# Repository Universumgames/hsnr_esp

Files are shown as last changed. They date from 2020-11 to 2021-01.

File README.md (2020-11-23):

# Communication between Arduino Uno's through light

<sub>created by Tom Arlt, Florian Meyer, Henning Müller, Florian Körwer</sub>

This project is a simple Aduino Uno project for communication between two Arduinos via light and controlling them via a serial monitor.

## Installation
This project was created with PlatformIO, an extension for VS Code to write Arduino programs, compile and write the binaries to an Arduino.

To use our project, open the platformIO project, change the `upload_port` in `platformio.ini` to the port your arduino is plugged into and upload the program.

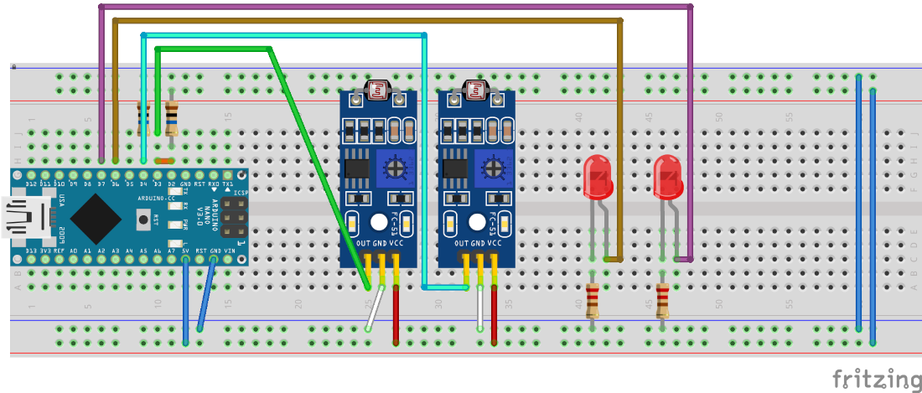
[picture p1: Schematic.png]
Wiring

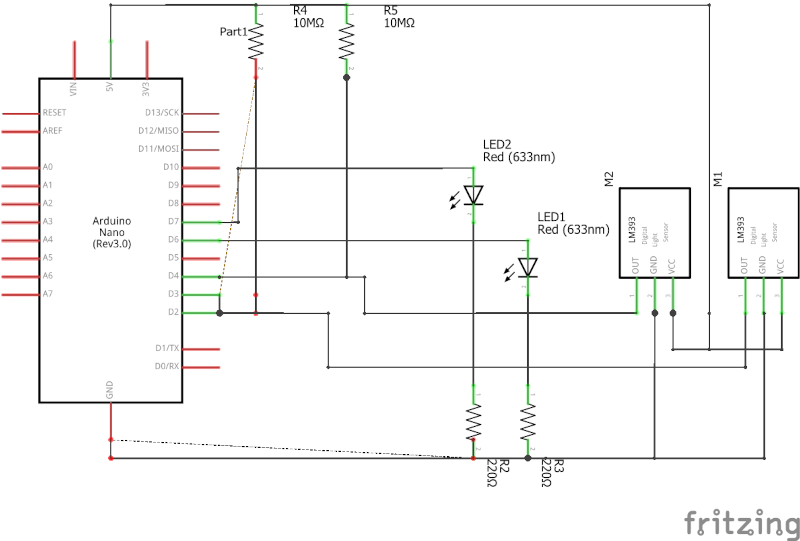
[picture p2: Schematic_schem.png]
Schematic


## Usage
1. Once uploaded, the arduino can communicate with another one as long as they are in LOS (Line of sight) and pointing directly at each other. The photoresistor should be facing the leds, to achieve that, the legs problably have to be bent.
2. Once placed correctly, you can start to open a serial monitor. You could use the integrated serial monitor in PlatformIO, the integrated serial monitor in the [Arduino IDE](https://www.arduino.cc/en/software) or [Putty](https://www.putty.org/), a great tool for using all kinds of connectivity like Serial, SSH, Raw, Telnet and Rlogin, or one of it's successors.
3. Select the Port your Arduino is plugged into, select the baud rate your arduino is sending/recieving to/from the serial monitor (the default is `9600`, but can be easily changed in `config.hpp`)
4. If everything works, you should be able to recieve encoded message from another Arduino and read the decoded result in your terminal, as well as write a message yourself and send it to the other Arduino.

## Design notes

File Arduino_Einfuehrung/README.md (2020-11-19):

# Arduino Einführung Aufgaben

## [Aufgaben-Datei](https://moodle.hsnr.de/pluginfile.php/640276/mod_resource/content/1/Anleitung_Kennenlernprojekte_WS2021_V3.pdf)

## Aufgabe 1

[Source-Code](https://git.ide3.de/universumgames/esp/-/tags/First-Task)

## Aufgabe 2

[Source-Code](https://git.ide3.de/universumgames/esp/-/tags/Second-Task)

## Aufgabe 3

[Source-Code](https://git.ide3.de/universumgames/esp/-/tags/Third-Task)

### 3 d) Geschwindigkeit von (Ultra-)Schall
Geschwindigkeit von Untraschall in Luft

    Mach 1 = 1234,8 km/h = 343 m/s

### 3 e)
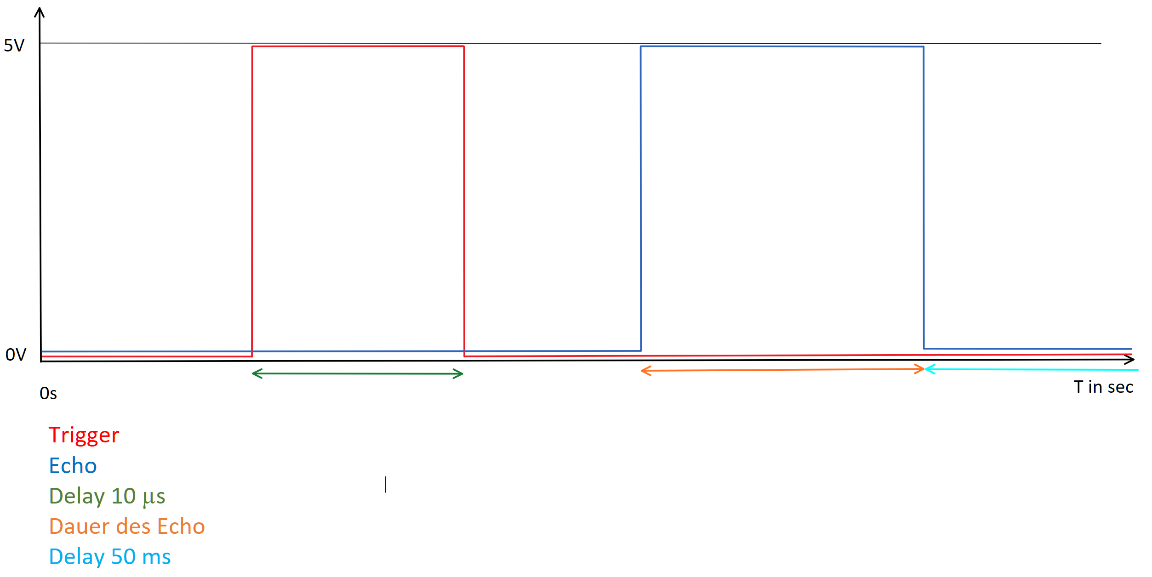
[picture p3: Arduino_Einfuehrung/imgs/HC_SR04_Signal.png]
HC-SR04 Signal

In der oben Abgebildeten Grafik ist ist die Verwendung bzw. eine Messung des HC-SR04 Ultraschallsensors abgebildet. In Rot dargestellt ist hierbei der `Trigger` Pin wohingegen Blau den `Echo` Pin repräsentiert. Nachdem der Trigger Pin für mindestens 10 µs auf 5V gesetzt wird, setzt der Sensor kurz darauf den Echo Pin ebenfalls auf 5V. In diesem Augenblich wird ein Ultrascahllsignal ausgesendet, sobald das Echo jenes gemessen wird, wird der Echo Pin wieder auf 0V gesetzt. Theoretisch kann der Ultraschallsensor mit einer Frequenz von maximal 50 Hz betrieben werden, welches einen Charge-Wechsel des Trigger Pins alle 20 ms bedeuten würde, jedoch kommt es in der Praxis immer auf die Entfernung und somit auf die Dauer des Echo Signals an, wie viel weniger häufig der Sensor die Entfernung pro Sekunde messen kann. Während die Frequenz, um es zu wiederholen, 50 Hz, ist die Amplitude des Signals bei 5V, die Periode läge bei einer Frequenz con 50 Hz somit bei 40 ms.

### 3 f) Ablauf einer Entfernungsmessung
Um die Entferung mittels Ultraschall messen zu können, wird im Prinzip ein kleiner Ultraschalllautsprecher und ein dazugehöriges Mikrofon verwendet. Der Mikrokontroller auf dem Entfernungsmesser sendet bei Eingang eines Signals über den `Trigger`-Pin Ultraschallwellen aus und empfängt ein Echo. Mithilfe der SChallgeschwindigkeit (343 m/s) und der vergangenen Zeit seitdem der Schall ausgesendet worden ist, kann die Entfernung zum Objekt unmittelbar (2-300cm) vor dem Ultraschallsensor errechnet werden. Das Ergebnis dieser Rechnung wird letztendlich über den `Echo`-Pin an den Arduino gesendet. Die `PulseIn()` Funktion des Arduinos wird beim Empfang des Signals verwendet, da die Daten nur über ein Kabel (`Echo`) gesendet werden und speziell "encodiert" sind. Der HC-SR04, so wie der Chip des Ultraschallsensors heißt, stellt den Pin `Echo` proportional (um den Wert 0.017) zur Entfernung auf HIGH (5V). Mithilfe der `PulseIn()` Methode des Arduinos kann die Dauert dieses Wertes gemessen werden und wird letzendlich von der Methode zurückgegeben.

## Aufgabe 4

[Source-Code](https://git.ide3.de/universumgames/esp/-/tags)

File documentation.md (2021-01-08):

# Dokumentation der Arduino Photokommunikation <br><sub>von Tom Arlt, Florian Körwer, Florian Meyer, Henning Müller, Cong Tai Phan <br><sub>Hochschule Niederrhein FB03, der 03.01.2021</sub></sub>

## Links
- [GitHub link](https://github.com/Universumgames/hsnr_esp)
- [IDE3 link](https://git.ide3.de/universumgames/esp)

## Einleitung
Unsere Aufgabe war es als Gruppe für das Erstsemesterprojekt, im folgenenden "ESP" genannt, zwei Arduinos mithilfe von Leds und Photoresistoren miteinander kommunizieren zu lassen und unsere Arbeit hiermit zu dokumentieren. <br>
Die notwendigen Bauteile wurden uns hierfür pro Person von der Hochschule zur Verfügung gestellt: 
- 1x Arduino Uno
- 2x LM392 mit Photoresistor und Potenziometer
- 1x Breadboard
- 2x 330 Ohm Widerstände
- verschied. LEDs
- verschied. Kabel für das Breadboard
- <s>1x Potenziometer</s>
- <s>1x Ultraschallsensor</s>

Da der Wissensstand innerhalb der Gruppe zum Thema Arduino sehr verschieden war, wurde nur zeitgleich und immer gemeinsam gearbeitet. Die Teilenhmer, welche bereits einiges an Erfahrung mit sich brachten, fungierten eher als Lehrpersonen, die den anderen das nötige Wissen überschaubar vermittelt haben, sodass alle dann gemeinsam die Aufgaben bearbeiten konnten.

## Lösung der Aufgabe
### Strategie
Das Entwickeln der Strategie für die Kommunikation, zu versuchen bereits bestehende Protokolle (als Basis) zu verwenden, war schnell erledigt. Der Versuch die nativen Protokolle des Arduinos zu verwenden scheiterte jedoch schnell, da alle Standardprotokolle viel zu schnell sind um mit LEDs verwendet werden zu können. Hinzukommt, dass uns zunächst entangen ist, dass der LM392 das Signal negiert ausgibt, welches uns erst einiges später auffiel. Schließlich entschlossen wir uns für eine serielle Kommunikation auf Basis des Protokolls [I2C](https://en.wikipedia.org/wiki/I%C2%B2C). Dieses Protokoll ist bei fast jedem modernen Microprocessor Hardwaremäßig implementiert für eine schneller Kommunikation. Bei diesem Protokoll ist in der Regel ein "Master" deklariert und mehrere "Slaves" welche alle gemeinsam an zwei Datenleitungen angeschlossen sind: "Data" und "Clock". Immer wenn die Spannung auf "Clock" von 0V auf 3.3/5V ändert wird auf "Data" der Zustand (Bit) abgelesen, bis sich letztendlich, nach einigen Takten ein Byte (8 Bit) ergeben. Das Standardprotokoll arbeitet eigentlich mit Adressen um zu differnezieren an wen und von wem die Nachricht gesendet wurde. <br>
Unser Protokoll übernimmt dabei nur das Prinzip von "Data" und "Clock", somit kann ein Empfangsmodul nur mit einem Sendermodul verbunden werden und vice versa.

### Unsere Hardware (Schematics)
Hier einmal die Schematics in der Arduino Schematic Software [fritzing](https://fritzing.org/)<br>



In dieser Schematic wurde der zum Arduino Uno funktionsidentische Arduino Nano verwendet und die Grafik übersitchlicher und kompakter zu gestalten. Beide Arduinoversionen besitzen denselben Prozessor (ATmega328P) und dieselben Pins. Die einzigen Unterschiede beider sind zum einen der Formfakor und zum anderen die Möglichkeit des Nanos, direkt auf ein Breadboard gesteckt werden zu können.
Dargestellt wurde hier ein einzelner Arduino, der in der Lage ist sowohl zu Empfangen als auch zu Senden, wenn das passend aufgebaute Gegenstück existiert.

### Software

Unser Programm wurde in C++ für die Arduino IDE geschrieben, schaue man sich frühere Commits an (vor dem 18.12.2020) wurde noch für eine andere IDE gechrieben: PaltformIO welche zwar auf der Arduino IDE basiert, jedoch hier nur eine Extension für die IDE VS Code ist. Einfacheitshalber wurde jedoch entgültig zur Arduino IDE gewechselt.

LED_SendSimple.ino
```cpp
//init variables
int LED = 2;
int incomingByte, ByteToSend;
int SerialCounter = -1;
//serial input buffer used as a stack
int SerialBuffer[10];
int MaxValue = 4;
int ClockCounter = 0;
boolean state = 0;
int BitsToSend = -1;

void setup() {
  //init serial interface
  Serial.begin(9600);
  pinMode(LED, OUTPUT);
}

void loop() {
  //read serial input if available
  if(Serial.available() > 0){
    incomingByte = Serial.read();
    if (incomingByte >= 32){
      //increment serial counter
      SerialCounter++;
      //store recieved byte from serial into stack buffer
      SerialBuffer[SerialCounter] = incomingByte;
    }
  }
  //theoratically the clockcounter could be removed and the delay in the last line set to 4*x
  ClockCounter++;
  if(ClockCounter >= MaxValue){
    ClockCounter = 0;
    state = !state;
    //if serial buffer is not empty
    if(SerialCounter > -1){
      //if current byte to send is not set
      if(BitsToSend <= -1){
        //set byte to send
        BitsToSend = SerialBuffer[SerialCounter];
        Serial.print("Sending byte: ");
        Serial.println(BitsToSend);
      }else{
        digitalWrite(LED, state);
        delay(70);
        //if led is on
        if(state){
          //decrease bit to send
          BitsToSend--;
          //if byte is sent, finish transmission
          if(BitsToSend <= 0){
            BitsToSend = -1;
            SerialCounter--;
            //wait same time as in outer loop, to avoid flickering of last count
            delay(4*70);
            digitalWrite(LED, LOW);
            delay(5000);
          }
        }
      }
    }
  }
  delay(70);
}
```

LED_RecieveSimple.ino
```cpp
//init variables
int LDR = 2;
int ClockCounter = 0;
int FlashCounter = 0;
int MaxValue = 2500;
int HighFlanke = 0;
int Flash;
unsigned long long lastmillis = 0;
int skippedMillis = 0;

void setup()
{
  //init serial monitor
  Serial.begin(9600);
  //init pinmode
  pinMode(LDR, INPUT);
}

void loop()
{
  ClockCounter++;
  //read LDR value
  Flash = digitalRead(LDR);
  //if led is off
  if (Flash)
  {
    HighFlanke = 1;
  }
  //if LDR value changes from HIGH to LOW
  if (!Flash && HighFlanke)
  {
    HighFlanke = 0;
    //increment flashcounter
    //account for glitches (glitches most often split a flash into two flashes)
    long delta = millis() - lastmillis;
    if (delta >= 500 || skippedMillis >= 500)
    {
      //increment counter and reset other variables
      FlashCounter++;
      ClockCounter = 0;
      skippedMillis = 0;
    }
    else
    {
      //to avoid glitches to impact transmission
      skippedMillis += delta;
    }
    //debug messages
    Serial.print(FlashCounter);
    Serial.print(": ");
    Serial.print(delta);
    Serial.print("ms ");
    Serial.println(skippedMillis);
    lastmillis = millis();
  }
  //if transmission for one character finished
  if (ClockCounter >= MaxValue && FlashCounter > 0)
  {
    //write flashcounter as character
    Serial.write(FlashCounter);
    //write ascii value
    Serial.println(FlashCounter);
    //reset flashcounter for next character
    FlashCounter = 0;
  }
  else
    delay(1);
}
```

#### Funktionsweise von Simple(Send/Recieve)
Die Funktionsweise von LED_SendSimple.ino basiert auf einer seriellen Datenübertragung. Um ein Zeichen zu übertragen wird dazu der byte Zahlenwert übermittelt. Dazu bleibt die LED x Millisekunden an und x Millisekunden aus, in unserem fall jeweils ca. 350. Nach vollständigem Durchzählen eines Bytes wird die Übertragung dieses mit einer sechs sekündigen Wartezeit abgeschlossen. <br>
Auf der Empfangsseite wird dabei auf ein eintreffendes Signal gewartet. Wenn mit einem Abstand von mindestens 500 ms ein Blinken erkannt wird, wir der derzeige Byte-Wert um eins erhöht, falls die Delta Zeit geringer ist, wird eine separate Variable erhöht. Durch das Verwenden der Deltazeit und dem Abfragen dieser zusätzliche Zeitvariable, wird der Einfluss von Glitches und Hazards bestmöglich minimiert. Bei einer Deltazeit von mehr als 2,5 Sekunden wird die Übteragung dieses Bytes abgeschlossen und dieser wird ausgegeben. 

LightCom.ino (LED_RecieveSynchron.ino + LED_SendSynchron) (eigene Lösung)
```cpp
//declare variables
//declare pins
int sender_clock = 5;
int sender_data = 6;
int reciever_clock = 2;
int reciever_clock_2 = 3;
int reciever_data = 4;

int incomingByte = 0;
long long last_millis = 0;
byte temp = 0;
int recieve_index = 7;
byte b = 0;
bool lastClockState = 0;

//declare timing
int ledDuration = 300;
int minSignalDur = 100;
int clDelay = 50;

void setup()
{
  //initialize Serial Monitor
  Serial.begin(9600);
  //set pin modes
  pinMode(sender_clock, OUTPUT);
  pinMode(sender_data, OUTPUT);
  pinMode(reciever_clock, INPUT);
  pinMode(reciever_clock_2, INPUT);
  pinMode(reciever_data, INPUT);
}

void loop()
{
  //check if serial queue contains items
  if (Serial.available() > 0)
  {
    //read incoming byte (characters)
    incomingByte = Serial.read();
    
    Serial.write(incomingByte);
    Serial.print(": ");
    Serial.print(incomingByte);
    Serial.print(" ");
    //send each bit seperately to serial monitor for debugging and to other arduino
    for (int i = 7; i >= 0; i--)
    {
      sendBit(bitRead(incomingByte, i));
    }
    Serial.println();
  }

//check for changes on clock pin
  bool state = !digitalRead(reciever_clock);
  if (state != lastClockState)
  {
     lastClockState = state;
     if (state == HIGH)
        clock_interrupt_start();
     else
        clock_interrupt_end();
  }
}

//read incoming bits
void clock_interrupt_start()
{
  bool dataval = !digitalRead(reciever_data);
  bitWrite(temp, recieve_index, dataval);
}

//verify incoming bit
void clock_interrupt_end()
{
  //calculate delta since clock fell, to check for hazards
  unsigned long delta = millis() - last_millis;
  //if delta > 100ms, it's nit a hazard or glitch from the photoresistor
  if (delta >= minSignalDur)
  {
    //write temporary byte to "longterm" byte
    b = temp;
    Serial.print(bitRead(b, recieve_index));
    //reduce recieve index to move to next bit
    recieve_index--;
    //if recieve_index < 0 we have successfully recieved a byte and print that to the serial monitor
    if (recieve_index < 0)
    {
      Serial.write(b);
      //reset recieving variables to default state
      recieve_index = 7;
      b = 0x0;
    }
    //reset for delta caluclation
    last_millis = millis();
  }
  else
  {
    //if a glitch was detected, delete temporarily recieved bit
    temp = b;
  }
}

//send single bit
void sendBit(bool bitt)
{
  Serial.print(bitt);
  //change data pin
  digitalWrite(sender_data, bitt);
  delay(clDelay);
  //change clock to HIGH
  digitalWrite(sender_clock, HIGH);
  //wait to be able to differentiate between valid bit and a hazard
  delay(ledDuration);
  //change both pins to default state
  digitalWrite(sender_clock, LOW);
  delay(clDelay);
  digitalWrite(sender_data, LOW);
  delay(ledDuration);
}

```

#### Funktionsweise von LightCom
Dieses Projekt ist ist für eine bidirektionale Kommunikation geeinget, d.h. beide Arduinos können miteinander kommunizieren. Die Kommunikation basiert auf dem simplen serieellen Protokoll namens I<sup>2</sup>C, bei dem zwei Verbindungen für eine serielle Datenübertragung verwendet werden. Diese Verbindungen heißen "Clock" und "Data" bzw. "SDA" (Serial Data) und "SCL" (Serial Clock). Bei der Modifikation dieses Protokolls wurde die Funktionsweise nicht verändert, jedoch musste das Verhalten des LDRs beachtet werden, da dieser Logisch negiert. Um nun einen Byte zu senden wird dieser Bitweise übertragen, dabei wird der MSB als erstes gesendet und die Übertragung eines Bytes endet mit dem LSB. Das Übermitteln eines einzelnen Bits erfolgt dabei wiefolgt: Die "Data"-LED wird auf den jeweiligen Wert des Bits gesetzt (HIGH für 1 und LOW für 0), nach einem kurzeln Delay, um sicherzustellen, dass die LED ihre gewünschte Helligkeit erreicht hat, wird die "Clock"-LED auf HIGH gesetzt, kurze Zeit später werden beide LEDs, unabhänging von ihrem vorherigen Zustand, wieder auf LOW gesetzt. Nach dem Empfangen von 8 Bits, bereits entsprechend dem MSB und LSB in einem Byte gespeichert, werden diese als ASCII Buchstabe auf dem Seriellen Monitor ausgegeben.

Link zum Aktuellen Programmcode: [Github](https://github.com/Universumgames/hsnr_esp/tree/master/LightCom), [IDE3](https://git.ide3.de/universumgames/esp/-/tree/master/LightCom) <br>
Link zum aufbereiteten/alternativen Code (eigenständig entwickelt von Tom Arlt):  [Github](https://github.com/Universumgames/hsnr_esp/tree/universumgames/LightCom), [IDE3](https://git.ide3.de/universumgames/esp/-/tree/universumgames/LightCom)

## Verwendung
(Übersetzt und aufbereitet aus [Readme.md](Readme.md))
Um unser Projekt zu verwenden, müssen zwei Schaltungen aufgebaut sein, wobei mindestens zwei LEDs und zwei Empfänger aufgebaut sein müssen, um zumindest die Einseitige Kommunikation testen zu können. Zu beachten ist, dass jedes LED-LM392 Paar zu allen anderen Paaren abgeschirmt sein sollte, da es sonst zu Interferrenzen kommen kann. Zudem muss das Potenziometer des LM392 eingestellt werden nur die dazugehörige eingeschaltete LED zu erkennen und nicht das Umgebungslicht. Bei der Erstellung der LED-LM392 Paare ist auf die Unterscheidung zwischen "Data" und "Clock" zu achten:
<pre>
Arduino 1       <-> Arduino 2
sender_clock    <-> reciever_clock
sender_data     <-> reciever_data
reciever_clock  <-> sender_clock
reciever_data   <-> sender_data
</pre>

Ist das Programm einmal auf beiden Arduinos hochgeladen, ist die Arduino IDE (o.ä.) nicht mehr notwendig. Nun kann über einen Seriellen Monitor, wie zum Beispiel der intergrierte Monitor der [Arduino IDE](https://www.arduino.cc/en/software) oder  [Putty](https://www.putty.org/) über den Arduino kommuniziert werden. In diesen Tools muss noch der Port, über den der Arduino angeschlossen ist, angegeben werden, sowie die Baud Rate des Seriellen Monitor, welche hier `9600` beträgt.

## Reflexion
Wie schon in `Strategie` erwähnt, war die grundsätzliche Strategie schnell gefunden, nur das ausarbeiten hat, dank der Rückschläge, etwas länger gedauert.
Nach den ersten Rückschlägen und das Festsetzen auf die entgültige Implementationsstrategie war auch das Entwickeln eines ersten Gerüsts relativ straight forward. Das Debuggen sowie ein ordentlicher Aufbau der Schaltung war dann die größere Herausforderung. Da durch ständig wechselnde Lichtverhältnisse der Photoresistor nicht immer wie gewünscht funktionierte, verzögerte sich das Programm-Debuggen ungemein. Erst nach vielen Stunden rumgrübelns, rumschrauben und ausprobieren, stellte sich als einzige zuverlässige Methode eine eigene Blackbox für jedes LED-LM392 Paar heraus. 

## Zusammenfassung
Die Aufgaben waren, wenn auch leicht missverständlich organisiert, einfach zu bearbeiten. Wir hatten schnell eine grundsätzliche Strategie für die Programmentwicklung gefunden und hatten binnen einiger Stunden nach den Fehlversuchen einen ersten ordentlichen Prototypen stehen. Somit hatten wir die grundsätzliche Aufgabe "zwei Arduinos mithilfe von LEDs und LDRs kommunizieren zu lassen" gelöst. Währenddessen sich die Ersten bereits an die Dokumentation gesetzt hatten, haben sich andere im Internet auf die Suche gemacht ein angemessenes Schematic-Tool ausfindig zu machen und eine digitale Schaltung zu erstellen.<br>
Erst später, als alle gemeinsam an der Dokumentation arbeiteten, fiel auf, dass die Aufgaben der Anleitung zum Kommunikationssystem zu bearbeiten sind. Als die Dokumentation bereits in den letzten Zügen war, wurden die zusätzlichen Aufgaben fertiggestellt, dabei schafften wir es jedoch nicht die Kommunikation der Arduinos mithilfe dieser Aufgaben über die digitalen Kommunikationswege erfolgreich zu realisieren, da die Photoresistoren die LEDs nur unzureichend erkennen konnten. Zusätzlich kamen noch Timingproblemen hinzu, die durch die Kommunikation entstanden sind.<br>
Ingesamt hat die Gruppe gut zusammengearbeitet und ist recht zügig zu einer ersten Lösung gekommen.

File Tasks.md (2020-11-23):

# Tasks
## 1. Arduino Einführung
Die einführenden Beispiel-Aufgaben sind beim zweiten Präsenztermin vorzuführen. D.h, jedes Gruppenmitglied hat die Schaltungen aufgebaut, den Arduino programmiert und kann das Ergebnis vorführen und erläutern.

## 2. Kommuniktaion zwischen zwei Arduinos
Aufgabe des Projekts ist es, eine optische Kommunikation aufzubauen. Dazu sollen mit einer oder mehrerer LEDs Informationen gesendet werden, in dem diese in einem bestimmten Muster ein- und ausgeschaltet werden. Ein optischer Sensor soll als Empfänger das Ein- und Ausschalten erkennen und die Informationen wiedergeben. 

### Dokumentation
Die Arbeiten zur optischen Kommunikation sind zu dokumentieren. Erstellen Sie als Gruppe ein Dokument (pdf) und laden es hier in Moodle eine Woche vor Ihrem dritten Präsenztermin hoch. Bitte halten Sie sich dabei an den folgenden Aufbau (ca. 5 Seiten):

- Titel der Dokumentation, Name der Hochschule/Fachbereich, Namen der Teammitglieder, Datum
- Einleitung (mit Aufgabenstellung)
- Aufgabenverteilung und Arbeitsweise in der Gruppe
- Wer hat was gemacht?
- Wurde nur gemeinsam gearbeitet oder gab es Arbeitspakete (z. B. zwei kümmern sich um den Sender und die anderen zwei um den Empfänger)?
- Beschreibung der Lösung
    - Strategie: verfolgte Lösungsidee
    - Hardware: Schaltplan
    - Software: Code mit Kommentaren
- Reflexion
    - Was hat gut funktioniert?
    - Was hat nicht so gut funktioniert und wie könnte man es beim nächsten Mal besser machen?
- Zusammenfassung

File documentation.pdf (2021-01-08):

documentation.md | 1/8/2021

# Dokumentation der Arduino Photokommunikation

von Tom Arlt, Florian Körwer, Florian Meyer, Henning Müller,

## Cong Tai Phan

## Hochschule Niederrhein FB03, der 03.01.2021

## Links

GitHub link (https://github.com/Universumgames/hsnr_esp)
IDE3 link (https://git.ide3.de/universumgames/esp)

## Einleitung

Unsere Aufgabe war es als Gruppe für das Erstsemesterprojekt, im folgenenden "ESP" genannt, zwei Arduinos mithilfe von Leds und Photoresistoren miteinander kommunizieren zu lassen und unsere Arbeit hiermit zu dokumentieren.
Die notwendigen Bauteile wurden uns hierfür pro Person von der Hochschule zur Verfügung gestellt:

1x Arduino Uno
2x LM392 mit Photoresistor und Potenziometer
1x Breadboard
2x 330 Ohm Widerstände
verschied. LEDs
verschied. Kabel für das Breadboard
1x Potenziometer
1x Ultraschallsensor

Da der Wissensstand innerhalb der Gruppe zum Thema Arduino sehr verschieden war, wurde nur zeitgleich und immer gemeinsam gearbeitet. Die Teilenhmer, welche bereits einiges an Erfahrung mit sich brachten, fungierten eher als Lehrpersonen, die den anderen das nötige Wissen überschaubar vermittelt haben, sodass alle dann gemeinsam die Aufgaben bearbeiten konnten.

## Lösung der Aufgabe

Strategie

Das Entwickeln der Strategie für die Kommunikation, zu versuchen bereits bestehende Protokolle (als Basis) zu verwenden, war schnell erledigt. Der Versuch die nativen Protokolle des Arduinos zu verwenden scheiterte jedoch schnell, da alle Standardprotokolle viel zu schnell sind um mit LEDs verwendet werden zu können. Hinzukommt, dass uns zunächst entangen ist, dass der LM392 das Signal negiert ausgibt, welches uns erst einiges später auffiel. Schließlich entschlossen wir uns für eine serielle Kommunikation auf Basis des Protokolls I2C. (https://en.wikipedia.org/wiki/I%C2%B2C) Dieses Protokoll ist bei fast jedem modernen Microprocessor Hardwaremäßig implementiert für eine schneller Kommunikation. Bei diesem Protokoll ist in der Regel ein "Master" deklariert und mehrere "Slaves" welche alle gemeinsam an zwei Datenleitungen angeschlossen sind: "Data" und "Clock". Immer wenn die Spannung auf "Clock" von 0V auf 3.3/5V ändert wird auf "Data" der Zustand (Bit) abgelesen, bis sich letztendlich, nach einigen Takten ein Byte (8 Bit) ergeben. Das Standardprotokoll arbeitet eigentlich mit Adressen um zu differnezieren an wen und von wem die Nachricht gesendet wurde.
Unser Protokoll übernimmt dabei nur das Prinzip von "Data" und "Clock", somit kann ein Empfangsmodul nur mit einem Sendermodul verbunden werden und vice versa.
Unsere Hardware (Schematics)

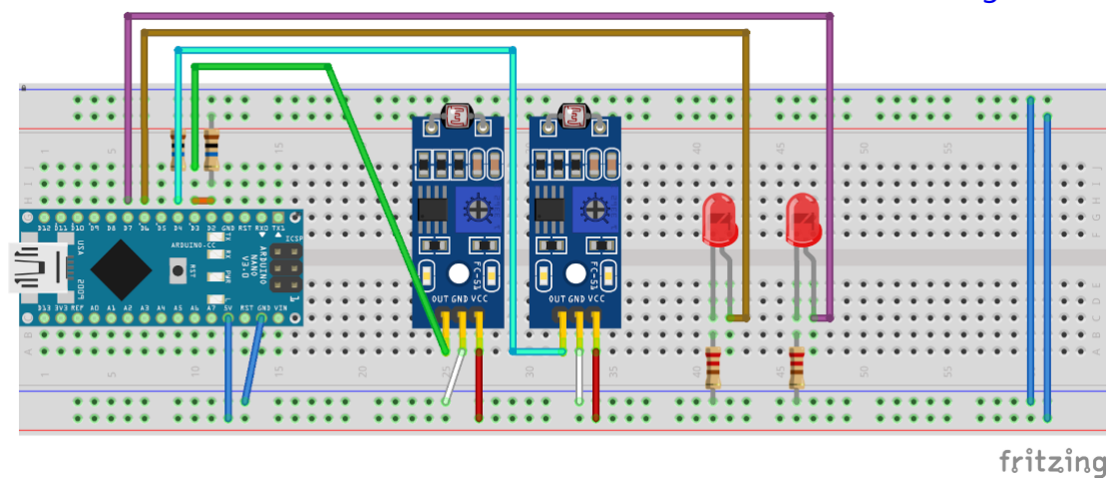
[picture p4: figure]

Hier einmal die Schematics in der Arduino Schematic Software fritzing (https://fritzing.org/)


In dieser Schematic wurde der zum Arduino Uno funktionsidentische Arduino Nano verwendet und die Grafik übersitchlicher und kompakter zu gestalten. Beide Arduinoversionen besitzen denselben Prozessor (ATmega328P) und dieselben Pins. Die einzigen Unterschiede beider sind zum einen der Formfakor und zum anderen die Möglichkeit des Nanos, direkt auf ein Breadboard gesteckt werden zu können. Dargestellt wurde hier ein einzelner Arduino, der in der Lage ist sowohl zu Empfangen als auch zu Senden, wenn das passend aufgebaute Gegenstück existiert.
Software

Unser Programm wurde in C++ für die Arduino IDE geschrieben, schaue man sich frühere Commits an (vor dem 18.12.2020) wurde noch für eine andere IDE gechrieben: PaltformIO welche zwar auf der Arduino IDE basiert, jedoch hier nur eine Extension für die IDE VS Code ist. Einfacheitshalber wurde jedoch entgültig zur Arduino IDE gewechselt.

LED_SendSimple.ino

//init variables
int LED = 2;
int incomingByte, ByteToSend;
int SerialCounter = -1;
//serial input buffer used as a stack int SerialBuffer[10];
int MaxValue = 4;
int ClockCounter = 0;
boolean state = 0;
int BitsToSend = -1;

void setup() {
//init serial interface
Serial.begin(9600);
pinMode(LED, OUTPUT);
}

void loop() {
//read serial input if available if(Serial.available() > 0){ incomingByte = Serial.read(); if (incomingByte >= 32){
//increment serial counter
SerialCounter++;
//store recieved byte from serial into stack buffer SerialBuffer[SerialCounter] = incomingByte;
}
}
//theoratically the clockcounter could be removed and the delay in the last line set to 4*x
ClockCounter++;
if(ClockCounter >= MaxValue){
ClockCounter = 0;
state = !state;
//if serial buffer is not empty if(SerialCounter > -1){
//if current byte to send is not set if(BitsToSend <= -1){
//set byte to send
BitsToSend = SerialBuffer[SerialCounter]; Serial.print("Sending byte: "); Serial.println(BitsToSend);
}else{
digitalWrite(LED, state);
delay(70);
//if led is on
if(state){
//decrease bit to send
BitsToSend--;
//if byte is sent, finish transmission if(BitsToSend <= 0){
BitsToSend = -1;

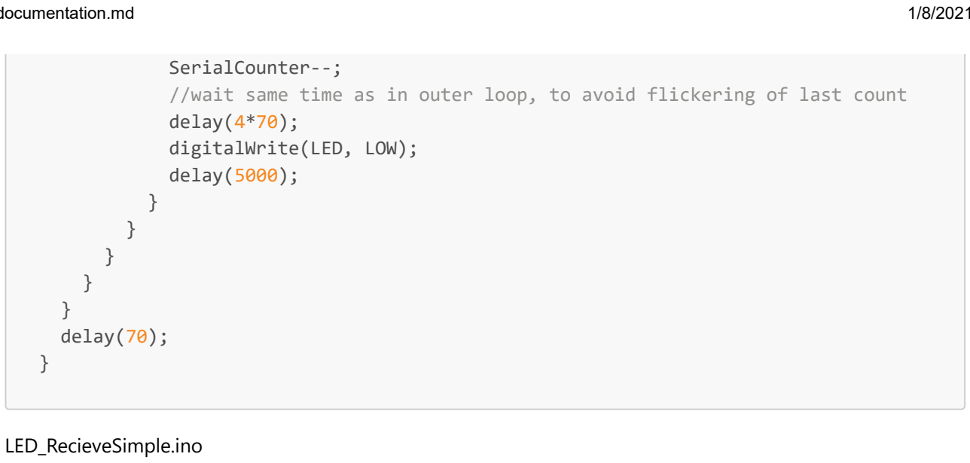
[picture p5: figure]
SerialCounter--;; delay(4*70); digitalWrite(LED, LOW); delay(5000);; } delay(70);; LED_RecieveSimple.ino

//wait same time as in outer loop, to avoid flickering of last count

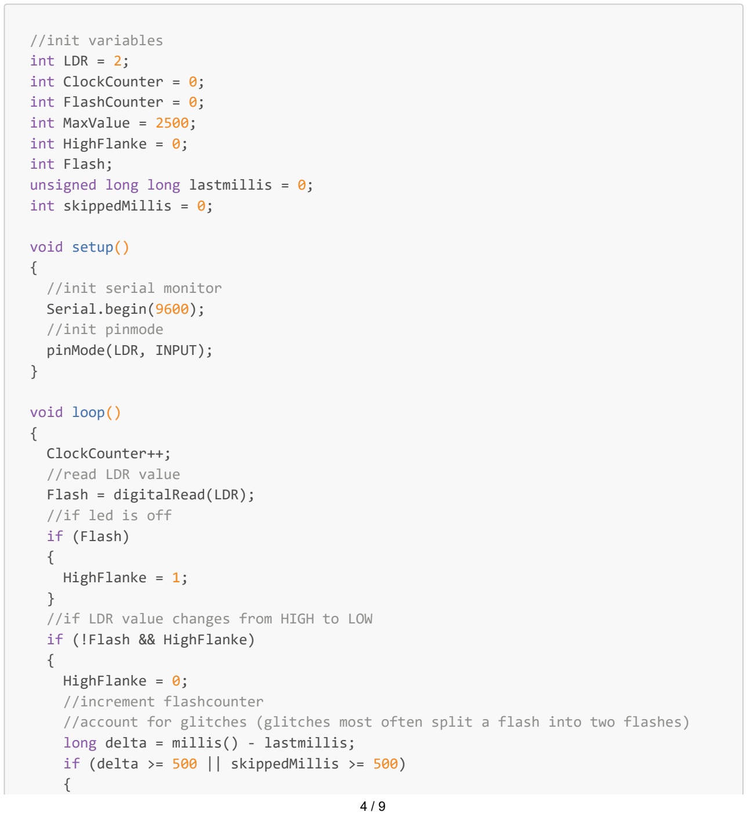
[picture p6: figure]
//init variables int LDR = 2; int ClockCounter = 0; int FlashCounter = 0; int MaxValue = 2500; int HighFlanke = 0; int Flash; unsigned long long lastmillis = 0; int skippedMillis = 0;; void setup() {; //init serial monitor Serial.begin(9600); //init pinmode pinMode(LDR, INPUT);; void loop() {; ClockCounter++; //read LDR value Flash = digitalRead(LDR); //if led is off if (Flash) {; HighFlanke = 1;; } //if LDR value changes from HIGH to LOW if (!Flash && HighFlanke) {; HighFlanke = 0; //increment flashcounter; long delta = millis() - lastmillis;

//account for glitches (glitches most often split a flash into two flashes)

if (delta >= 500 || skippedMillis >= 500)

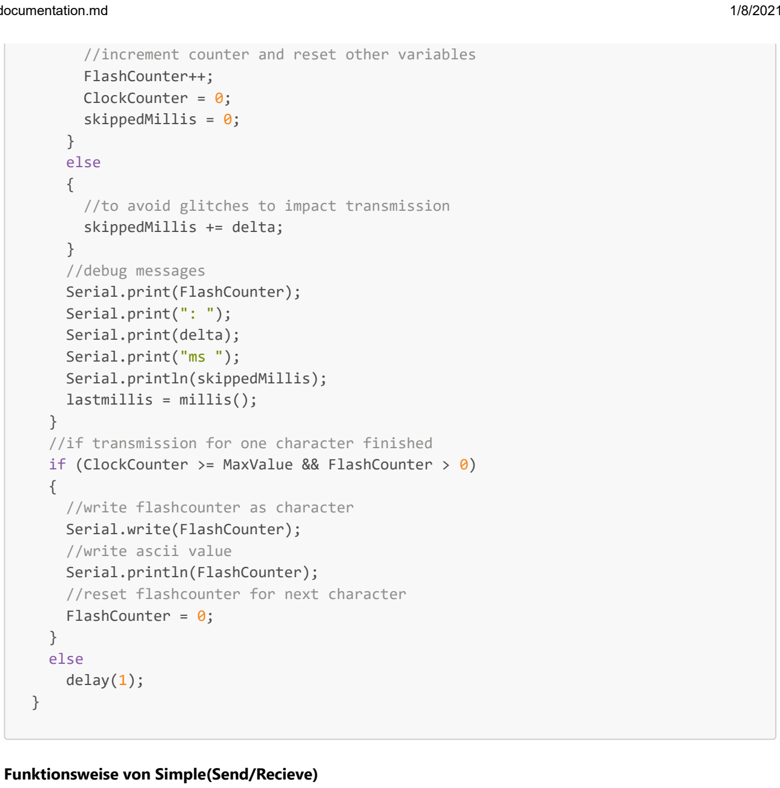
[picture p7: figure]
FlashCounter++; ClockCounter = 0; skippedMillis = 0;; } else {; skippedMillis += delta;; } //debug messages Serial.print(FlashCounter); Serial.print(": "); Serial.print(delta); Serial.print("ms "); Serial.println(skippedMillis); lastmillis = millis();; //write flashcounter as character Serial.write(FlashCounter); //write ascii value Serial.println(FlashCounter); //reset flashcounter for next character FlashCounter = 0;; } else delay(1);; Funktionsweise von Simple(Send/Recieve)

//increment counter and reset other variables

//to avoid glitches to impact transmission

//if transmission for one character finished
if (ClockCounter >= MaxValue && FlashCounter > 0)

Die Funktionsweise von LED_SendSimple.ino basiert auf einer seriellen Datenübertragung. Um ein Zeichen zu übertragen wird dazu der byte Zahlenwert übermittelt. Dazu bleibt die LED x Millisekunden an und x Millisekunden aus, in unserem fall jeweils ca. 350. Nach vollständigem Durchzählen eines Bytes wird die Übertragung dieses mit einer sechs sekündigen Wartezeit abgeschlossen.
Auf der Empfangsseite wird dabei auf ein eintreffendes Signal gewartet. Wenn mit einem Abstand von mindestens 500 ms ein Blinken erkannt wird, wir der derzeige Byte-Wert um eins erhöht, falls die Delta Zeit geringer ist, wird eine separate Variable erhöht. Durch das Verwenden der Deltazeit und dem Abfragen dieser zusätzliche Zeitvariable, wird der Einfluss von Glitches und Hazards bestmöglich minimiert. Bei einer Deltazeit von mehr als 2,5 Sekunden wird die Übteragung dieses Bytes abgeschlossen und dieser wird ausgegeben.

LightCom.ino (LED_RecieveSynchron.ino + LED_SendSynchron) (eigene Lösung)

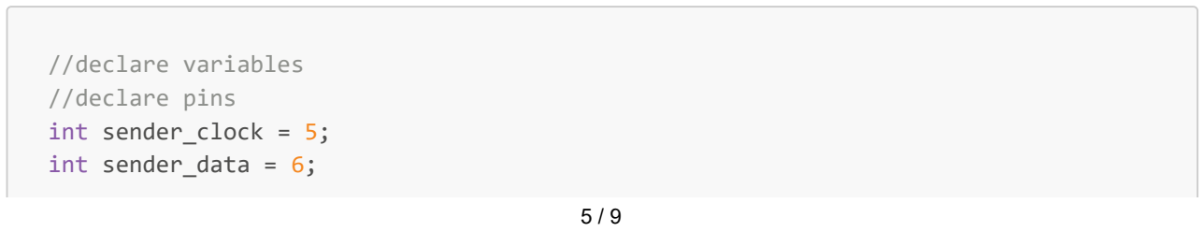
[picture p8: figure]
//declare variables //declare pins int sender_clock = 5; int sender_data = 6;

int reciever_clock = 2;
int reciever_clock_2 = 3;
int reciever_data = 4;

int incomingByte = 0;
long long last_millis = 0; byte temp = 0;
int recieve_index = 7;
byte b = 0;
bool lastClockState = 0;

//declare timing
int ledDuration = 300;
int minSignalDur = 100;
int clDelay = 50;

void setup()
{
//initialize Serial Monitor Serial.begin(9600);
//set pin modes
pinMode(sender_clock, OUTPUT); pinMode(sender_data, OUTPUT); pinMode(reciever_clock, INPUT); pinMode(reciever_clock_2, INPUT); pinMode(reciever_data, INPUT);
}

void loop()
{
//check if serial queue contains items if (Serial.available() > 0)
{
//read incoming byte (characters) incomingByte = Serial.read();

Serial.write(incomingByte); Serial.print(": ");
Serial.print(incomingByte);
Serial.print(" ");
//send each bit seperately to serial monitor for debugging and to other arduino
for (int i = 7; i >= 0; i--)
{
sendBit(bitRead(incomingByte, i)); }
Serial.println();
}

//check for changes on clock pin
bool state = !digitalRead(reciever_clock); if (state != lastClockState)
{
lastClockState = state;

if (state == HIGH)
clock_interrupt_start();
else
clock_interrupt_end();
}
}

//read incoming bits
void clock_interrupt_start()
{
bool dataval = !digitalRead(reciever_data); bitWrite(temp, recieve_index, dataval);
}

//verify incoming bit
void clock_interrupt_end()
{
//calculate delta since clock fell, to check for hazards
unsigned long delta = millis() - last_millis;
//if delta > 100ms, it's nit a hazard or glitch from the photoresistor if (delta >= minSignalDur)
{
//write temporary byte to "longterm" byte
b = temp;
Serial.print(bitRead(b, recieve_index));
//reduce recieve index to move to next bit
recieve_index--;
//if recieve_index < 0 we have successfully recieved a byte and print that to the serial monitor
if (recieve_index < 0)
{
Serial.write(b);
//reset recieving variables to default state recieve_index = 7;
b = 0x0;
}
//reset for delta caluclation last_millis = millis();
}
else
{
//if a glitch was detected, delete temporarily recieved bit temp = b;
}
}

//send single bit
void sendBit(bool bitt)
{
Serial.print(bitt);
//change data pin
digitalWrite(sender_data, bitt); delay(clDelay);
//change clock to HIGH digitalWrite(sender_clock, HIGH);
//wait to be able to differentiate between valid bit and a hazard delay(ledDuration);
//change both pins to default state
digitalWrite(sender_clock, LOW);
delay(clDelay);
digitalWrite(sender_data, LOW); delay(ledDuration);
}

Funktionsweise von LightCom

Dieses Projekt ist ist für eine bidirektionale Kommunikation geeinget, d.h. beide Arduinos können miteinander kommunizieren. Die Kommunikation basiert auf dem simplen serieellen Protokoll namens I²C, bei dem zwei Verbindungen für eine serielle Datenübertragung verwendet werden. Diese Verbindungen heißen "Clock" und "Data" bzw. "SDA" (Serial Data) und "SCL" (Serial Clock). Bei der Modifikation dieses Protokolls wurde die Funktionsweise nicht verändert, jedoch musste das Verhalten des LDRs beachtet werden, da dieser Logisch negiert. Um nun einen Byte zu senden wird dieser Bitweise übertragen, dabei wird der MSB als erstes gesendet und die Übertragung eines Bytes endet mit dem LSB. Das Übermitteln eines einzelnen Bits erfolgt dabei wiefolgt: Die "Data"-LED wird auf den jeweiligen Wert des Bits gesetzt (HIGH für 1 und LOW für 0), nach einem kurzeln Delay, um sicherzustellen, dass die LED ihre gewünschte Helligkeit erreicht hat, wird die "Clock"-LED auf HIGH gesetzt, kurze Zeit später werden beide LEDs, unabhänging von ihrem vorherigen Zustand, wieder auf LOW gesetzt. Nach dem Empfangen von 8 Bits, bereits entsprechend dem MSB und LSB in einem Byte gespeichert, werden diese als ASCII Buchstabe auf dem Seriellen Monitor ausgegeben.

Link zum Aktuellen Programmcode: Github, (https://github.com/Universumgames/hsnr_esp/tree/master/LightCom) IDE3 (https://git.ide3.de/universumgames/esp/-/tree/master/LightCom)
Link zum aufbereiteten/alternativen Code (eigenständig entwickelt von Tom Arlt): Github, (https://github.com/Universumgames/hsnr_esp/tree/universumgames/LightCom) IDE3 (https://git.ide3.de/universumgames/esp/-/tree/universumgames/LightCom)

## Verwendung

(Übersetzt und aufbereitet aus Readme.md) Um unser Projekt zu verwenden, müssen zwei Schaltungen aufgebaut sein, wobei mindestens zwei LEDs und zwei Empfänger aufgebaut sein müssen, um zumindest die Einseitige Kommunikation testen zu können. Zu beachten ist, dass jedes LED-LM392 Paar zu allen anderen Paaren abgeschirmt sein sollte, da es sonst zu Interferrenzen kommen kann. Zudem muss das Potenziometer des LM392 eingestellt werden nur die dazugehörige eingeschaltete LED zu erkennen und nicht das Umgebungslicht. Bei der Erstellung der LED-LM392 Paare ist auf die Unterscheidung zwischen "Data" und

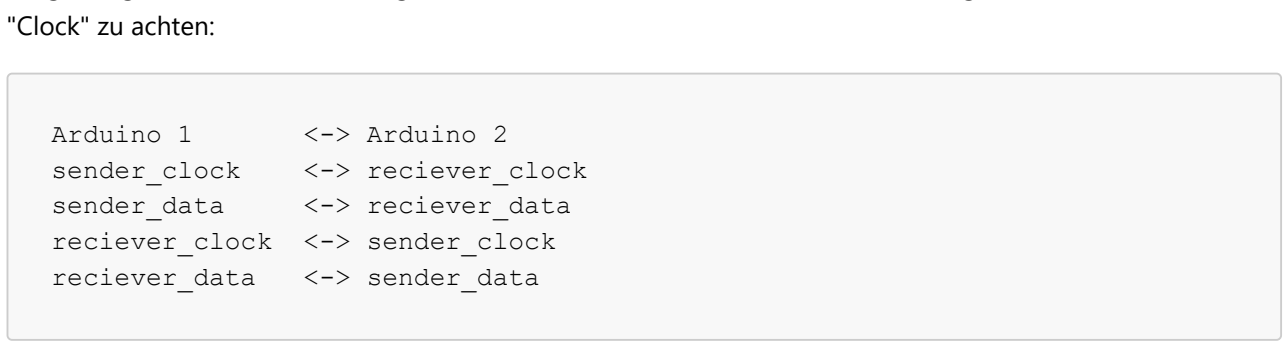
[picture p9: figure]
"Clock" zu achten:; Arduino 1; <-> Arduino 2; sender_clock; <-> reciever_clock; sender_data; <-> reciever_data; reciever_clock <-> sender_clock; reciever_data; <-> sender_data

Ist das Programm einmal auf beiden Arduinos hochgeladen, ist die Arduino IDE (o.ä.) nicht mehr notwendig. Nun kann über einen Seriellen Monitor, wie zum Beispiel der intergrierte Monitor der Arduino IDE (https://www.arduino.cc/en/software) oder Putty (https://www.putty.org/) über den Arduino kommuniziert werden. In diesen Tools muss noch der Port, über den der Arduino angeschlossen ist, angegeben werden, sowie die Baud Rate des Seriellen Monitor, welche hier 9600 beträgt.

## Reflexion

Wie schon in Strategie erwähnt, war die grundsätzliche Strategie schnell gefunden, nur das ausarbeiten hat, dank der Rückschläge, etwas länger gedauert. Nach den ersten Rückschlägen und das Festsetzen auf die entgültige Implementationsstrategie war auch das Entwickeln eines ersten Gerüsts relativ straight forward. Das Debuggen sowie ein ordentlicher Aufbau der Schaltung war dann die größere Herausforderung. Da durch ständig wechselnde Lichtverhältnisse der Photoresistor nicht immer wie gewünscht funktionierte, verzögerte sich das Programm-Debuggen ungemein. Erst nach vielen Stunden rumgrübelns, rumschrauben und ausprobieren, stellte sich als einzige zuverlässige Methode eine eigene Blackbox für jedes LED-LM392 Paar heraus.

## Zusammenfassung

Die Aufgaben waren, wenn auch leicht missverständlich organisiert, einfach zu bearbeiten. Wir hatten schnell eine grundsätzliche Strategie für die Programmentwicklung gefunden und hatten binnen einiger Stunden nach den Fehlversuchen einen ersten ordentlichen Prototypen stehen. Somit hatten wir die grundsätzliche Aufgabe "zwei Arduinos mithilfe von LEDs und LDRs kommunizieren zu lassen" gelöst. Währenddessen sich die Ersten bereits an die Dokumentation gesetzt hatten, haben sich andere im Internet auf die Suche gemacht ein angemessenes Schematic-Tool ausfindig zu machen und eine digitale Schaltung zu erstellen.
Erst später, als alle gemeinsam an der Dokumentation arbeiteten, fiel auf, dass die Aufgaben der Anleitung zum Kommunikationssystem zu bearbeiten sind. Als die Dokumentation bereits in den letzten Zügen war, wurden die zusätzlichen Aufgaben fertiggestellt, dabei schafften wir es jedoch nicht die Kommunikation der Arduinos mithilfe dieser Aufgaben über die digitalen Kommunikationswege erfolgreich zu realisieren, da die Photoresistoren die LEDs nur unzureichend erkennen konnten. Zusätzlich kamen noch Timingproblemen hinzu, die durch die Kommunikation entstanden sind.
Ingesamt hat die Gruppe gut zusammengearbeitet und ist recht zügig zu einer ersten Lösung gekommen.

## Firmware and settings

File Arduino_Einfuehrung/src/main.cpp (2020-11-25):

#include <Arduino.h>

//led pins
#define RED 6
#define GREEN 3
#define YELLOW 5
//ultrasonic sensor pins
#define TRIGGER 2
#define ECHO 4
//potentiometer
#define POT A0
//led offset
#define GREEN_END 400
#define GREEN_BEGIN 250
#define YELLOW_END 300
#define YELLOW_BEGIN 150
#define RED_END 200
#define RED_BEGIN 0

//if serial output is needed uncomment next line
//#define SERIAL_DEBUG true
//switch between pwm and default
#define USE_PWM

//1 == true == HIGH
//0 == false == LOW

int mappedVals[10] = {0};
int currentIndex = 0;

//set value for all LEDS
void allLED(bool value)
{
  digitalWrite(RED, value);
  digitalWrite(GREEN, value);
  digitalWrite(YELLOW, value);
}

void setSimpleLED(int value)
{
  allLED(LOW);
  if (value >= 0 && value <= 100)
  {
    digitalWrite(GREEN, HIGH);
  }
  else if (value > 100 && value <= 200)
  {
    digitalWrite(YELLOW, HIGH);
  }
  else if (value > 200)
  {
    digitalWrite(RED, HIGH);
  }
}

void setComplexLED(int pin, int mappedVal, int begin, int end)
{
  if (mappedVal >= begin)
  {
    double val = mappedVal - begin;
    double m = map(val, 0, end - begin, 0, 255);
    if (val > 0)
#ifdef USE_PWM
      analogWrite(pin, m);
#else
      digitalWrite(pin, HIGH);
#endif
#ifdef SERIAL_DEBUG
    Serial.print(m);
#endif
  }
#ifdef SERIAL_DEBUG
  Serial.println();
#endif
}

//get Distance from ultrasonic Sensor
double getDistance()
{
  long time = 0;
  double distance = 0;
  digitalWrite(TRIGGER, LOW);
  delayMicroseconds(2);
  digitalWrite(TRIGGER, HIGH);
  delayMicroseconds(10);
  digitalWrite(TRIGGER, LOW);
  time = pulseIn(ECHO, HIGH);
  distance = time * 0.017;
  delay(50);
  return distance;
}

void setup()
{
  //initialise Serial if needed
#ifdef SERIAL_DEBUG
  Serial.begin(9600);
  delay(500);
  Serial.println("G\t Y\t R");
#endif

  //define pin usage
  pinMode(RED, OUTPUT);
  pinMode(GREEN, OUTPUT);
  pinMode(YELLOW, OUTPUT);

  pinMode(TRIGGER, OUTPUT);
  pinMode(ECHO, INPUT);

  pinMode(POT, INPUT);
}

void loop()
{
  //turn all LEDs off
  double dist = getDistance();

  //Smooth transition between three leds
  double mappedVal = map(dist, 0, 37, 0, 370);
  mappedVals[currentIndex] = mappedVal;
  currentIndex++;

//average of last 10 measurements
  if (currentIndex >= 9)
  {
    currentIndex = 0;
    double avgVal = 0;
    for (int i = 0; i <= 9; i++)
    {
      avgVal += mappedVals[i];
    }
    avgVal /= 9;
    //set all LEDs off
    allLED(LOW);

    //set all three leds with pwm
    setComplexLED(RED, avgVal, RED_BEGIN, RED_END);
    setComplexLED(YELLOW, avgVal, YELLOW_BEGIN, YELLOW_END);
    setComplexLED(GREEN, avgVal, GREEN_BEGIN, GREEN_END);
  }
}

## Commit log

2020-11-11 added I2C clock pseed modifier
2020-11-18 fixed led flickering
2020-11-19 tried using "libraries" like built-in serial, I2C, own adaptation of I2C, but all failed due to imperfections between led state change and photoresistor latency and uncertanty
    [main.cpp]
2020-11-20 interrupt debounce test very simple
2020-11-20 got I2C adaptation running
2020-11-22 replacing interrupt, test
2020-11-23 added Schematic
    [Schematic.fzz]
2020-11-23 removed unnessecary file and changed filename
    [Schematic TwoLight Arduino Nano v3.fzz, Schematic.fzz]
